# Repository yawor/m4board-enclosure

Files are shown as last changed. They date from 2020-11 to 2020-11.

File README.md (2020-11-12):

# M4 Board Enclosures Generator

This project provides OpenSCAD files for creating 3d models of some revisions of M4 Board by Duke (https://spinpoint.org) for Amstrad CPC.

It uses a [PCB Enclosure Generator](https://github.com/yawor/openscad-pcb-enclosure-generator) library.

Currently supported board revisions revisions:
- 2.5C with an edge connector
- 2.5C with an idc connector (not tested)
- 2.5B with an edge connector (not tested)
- 2.5B with an idc connector (not tested)

Ready to use STL files can be found in stl directory.

## Customizing

To customize the enclosures, clone this repository using:
```sh
git clone --recursive https://github.com/yawor/m4board-enclosure.git
```

The PCB Enclosure Generator library is added as a git submodule in pcb_enclosure directory.

Each board revision is defined in its own OpenSCAD file.

The provided files use FontAwesome and Fredoka One fonts to render texts and symbols, which you should have installed on your system, unless you plan to change them to some other fonts. These fonts use SIL OFL 1.1 and are free to download and use.

## Printed case

Images show a printed case for M4 Board rev2.5c with an edge connector. It's printed with Prusa's Galaxy Black PLA, with inserts printed with Prusa's Galaxy Silver PLA on a Prusa Mini printer.

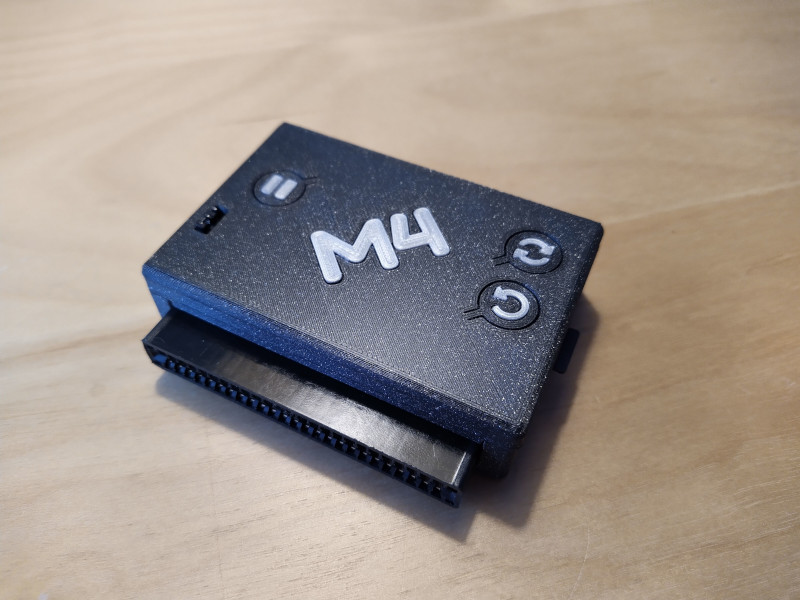
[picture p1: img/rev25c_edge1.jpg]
rev2.5c edge image1

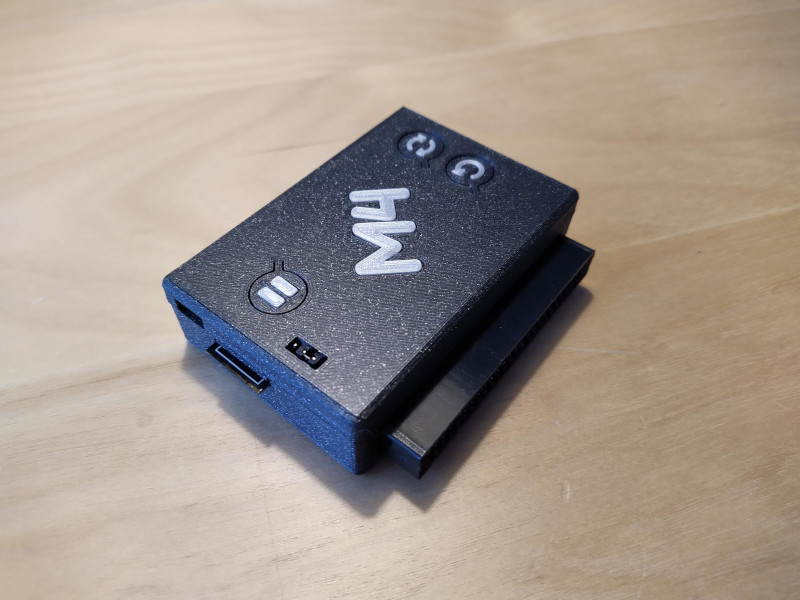
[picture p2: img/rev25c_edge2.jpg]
rev2.5c edge image2


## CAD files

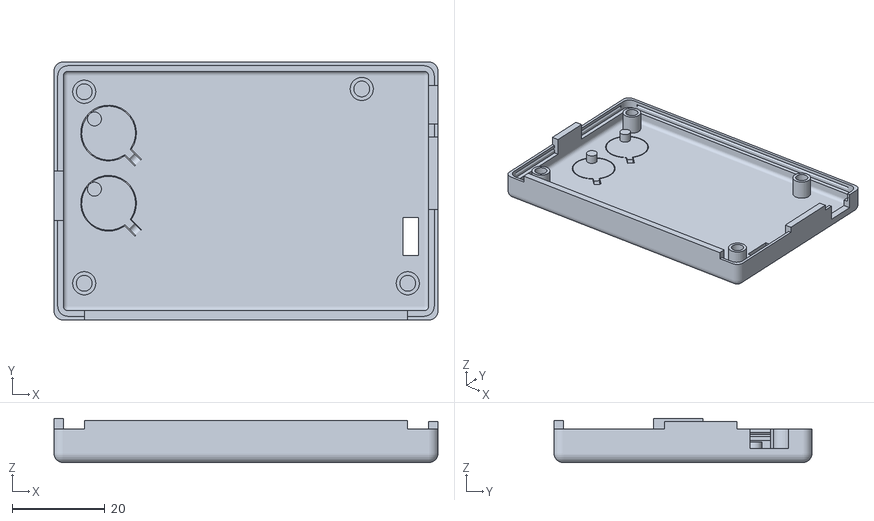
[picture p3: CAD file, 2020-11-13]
stl/m4board_rev2.5b_edge_top_notext.stl
82.6 x 55.5 x 9.50

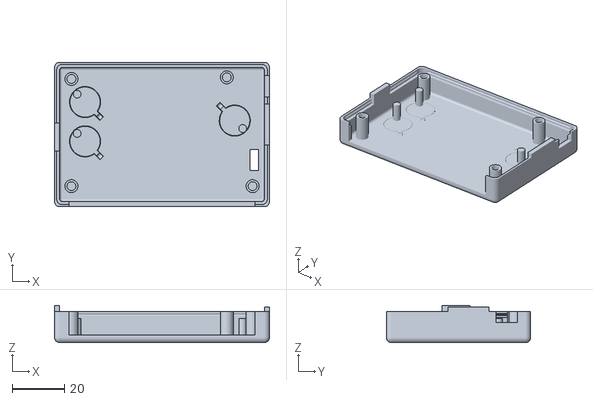
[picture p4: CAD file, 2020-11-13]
stl/m4board_rev2.5c_idc_top_notext.stl
82.6 x 55.5 x 14.3

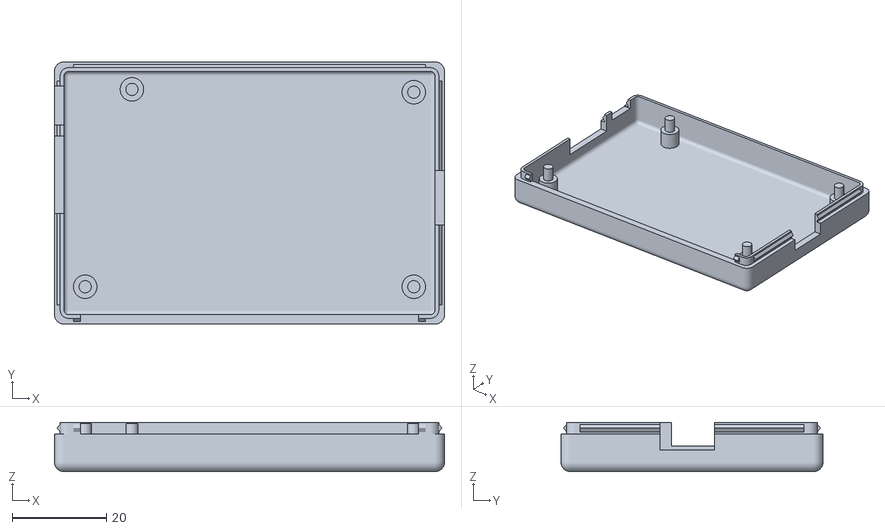
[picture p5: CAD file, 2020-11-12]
stl/m4board_rev2.5b_idc_bottom.stl
82.6 x 55.5 x 10.4

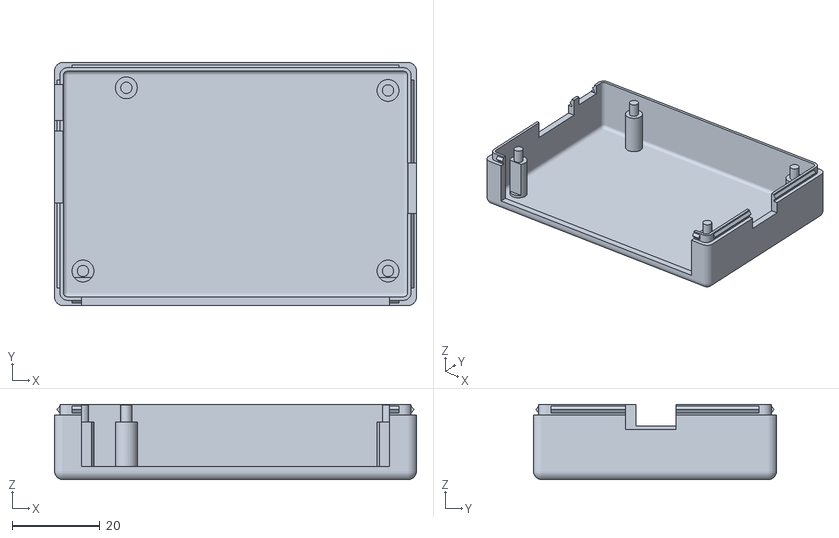
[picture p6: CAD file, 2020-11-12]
stl/m4board_rev2.5b_edge_bottom.stl
82.6 x 55.5 x 17.2

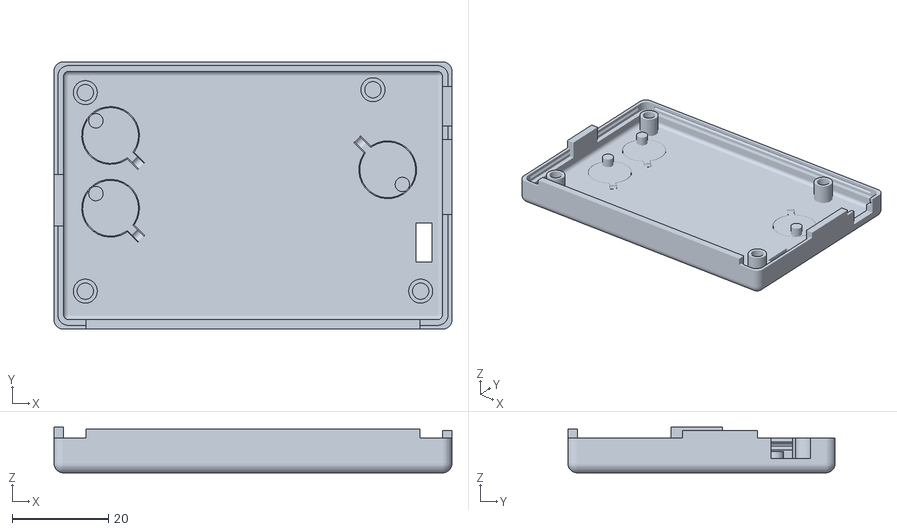
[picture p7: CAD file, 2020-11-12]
stl/m4board_rev2.5c_edge_top.stl
82.6 x 55.5 x 9.50

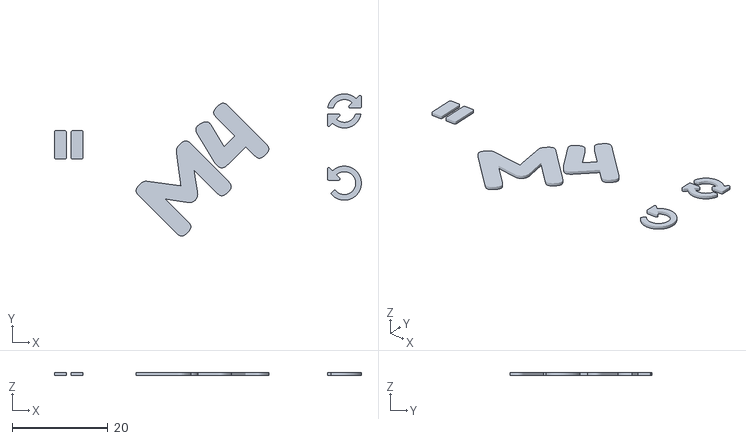
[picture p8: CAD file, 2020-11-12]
stl/m4board_rev2.5c_edge_texts.stl
64.2 x 29.7 x 0.61

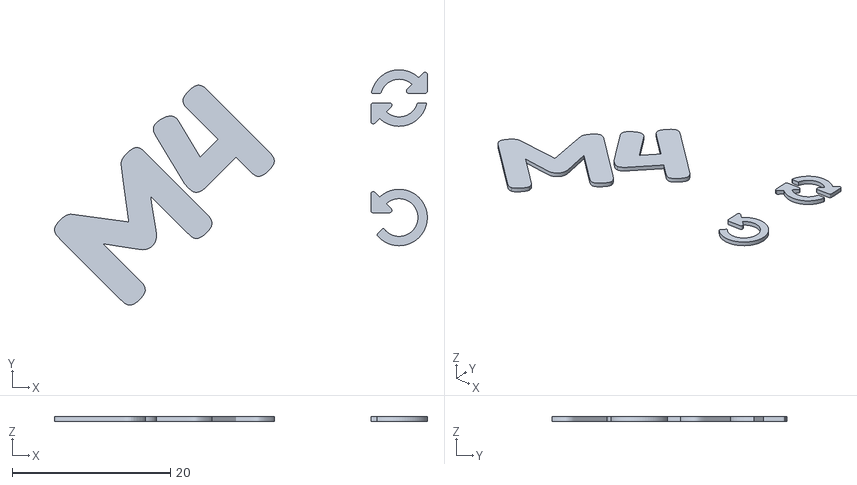
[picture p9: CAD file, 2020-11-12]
stl/m4board_rev2.5b_idc_texts.stl
47.1 x 29.7 x 0.61

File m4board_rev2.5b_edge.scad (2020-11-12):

/*
    Enclosure definition for M4Board rev 2.5B by Duke (https://www.spinpoint.org/)

    Copyright © 2020 Marcin Jaworski

    This program is free software: you can redistribute it and/or modify
    it under the terms of the GNU General Public License as published by
    the Free Software Foundation, either version 3 of the License, or
    (at your option) any later version.

    This program is distributed in the hope that it will be useful,
    but WITHOUT ANY WARRANTY; without even the implied warranty of
    MERCHANTABILITY or FITNESS FOR A PARTICULAR PURPOSE.  See the
    GNU General Public License for more details.

    You should have received a copy of the GNU General Public License
    along with this program.  If not, see <http://www.gnu.org/licenses/>
*/

use <pcb_enclosure/pcb_enclosure.scad>;

Assembled = true;
Export = "all"; // ["all", "top", "bottom", "texts"]
AddTexts = true;

/* [Hidden] */
$fn = 30;

m4Dim = [76.6, 49.5, 1.6];
m4CompBB = [[0, 0, 4], [m4Dim.x, m4Dim.y, -5]];
m4Slots = [
    ["left", [m4Dim.y - 12.7, -1.6], [m4Dim.y - 29.1, -2.6]], // antenna
    ["left", [m4Dim.y - 2.1, 4.2], [m4Dim.y - 10.3, -0.2]], // USB
    ["right", [m4Dim.y - 20, -2.3], [m4Dim.y - 31.5, -3.4]], // microSD
    ["front", [3.2, -1.9], [m4Dim.x - 3.2, -11.8]], // EXT
    ["top", [1.2, 19], [4.5, 10.9]], // power selection jumper
];
m4MountPosts = [
    [[13.4, m4Dim.y - 2.8], 3],
    [[m4Dim.x - 3.5, m4Dim.y - 3.4], 3],
    [[3.5, 4.9], 3],
    [[m4Dim.x - 3.5, 4.9], 3],
];
m4MountRestrictions = [
    [[0, 0, -12], [m4Dim.x, 3.4, -1.6]], // Area taken by the edge connector below the board
];
m4Buttons = [
    [[m4Dim.x - 5.7, m4Dim.y - 9.25], 2.8, -135], // M4board reset
    [[m4Dim.x - 5.7, m4Dim.y - 24.35], 2.8, -135], // CPC reset
];
m4Texts = AddTexts ? [
    [[m4Dim.x / 2, m4Dim.y / 2], "M4", "Fredoka One", 14, "center", "center", 45],
    [m4Buttons[0][0] - [3, -0.4], "\uf021", "FontAwesome", 6, "center", "top", 0], // symbol on M4board reset button
    [m4Buttons[1][0] - [3, -0.4], "\uf0e2", "FontAwesome", 6, "center", "top", 0], // symbol on CPC reset button
] : [];

PCBEnclosure(pcbDimensions=m4Dim, pcbComponentsBB=m4CompBB, mountPosts=m4MountPosts, mountPostsRestrictions=m4MountRestrictions, buttons=m4Buttons, slots=m4Slots, topTexts=m4Texts, textDepth=0.6, buttonDiameter=12, assembled=Assembled, export=Export);

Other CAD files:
stl/m4board_rev2.5c_edge_top_notext.stl
stl/m4board_rev2.5b_idc_top_notext.stl
stl/m4board_rev2.5c_idc_bottom.stl
stl/m4board_rev2.5b_edge_top.stl
stl/m4board_rev2.5c_idc_top.stl
stl/m4board_rev2.5c_edge_bottom.stl
stl/m4board_rev2.5b_idc_top.stl
stl/m4board_rev2.5b_bottom.stl
stl/m4board_rev2.5c_bottom.stl
m4board_rev2.5b_idc.scad
m4board_rev2.5c_edge.scad
m4board_rev2.5c_idc.scad
stl/m4board_rev2.5b_top.stl
stl/m4board_rev2.5c_top.stl

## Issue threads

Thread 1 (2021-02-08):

Way to configure the button gap size?

damieng, 2021-02-08:
Hi there, love the case and the files to create them but when I print the front face my buttons are stuck and even a knife isn't going to fix it - there's a gap on the inside of the case but the outside which was against the build plate is solid.

I couldn't see a way to configure the size of the gap around each button from the openscad file. Could that be made into a parameter for such a scenario?

yawor, 2021-02-08:
Hi,
This is probably printer dependent as I've had no issue printing this on my Prusa Mini.
If you check the pcb_enclosure.scad source, you'll see that `PCBEnclosure` module has a `buttonTolerance` argument. It's not being explicitly set from m4board_*.scad files so it uses a default value of 0.2 mm. You can either modify a default value in pcb_enclosure.scad or add your value in m4board_*.scad to `PCBEnclosure()` call.

damieng, 2021-02-09:
Thanks that looks like it has successfully modified things. I've tried doubling it to 0.4mm and will see how it prints tomorrow.

Closed 2021-02-09.

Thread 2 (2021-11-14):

Unable to print top buttons for the M4 board.

yagosan, 2021-11-14:
Hi.

I have made several tests with my Ender 3 Pro with 0.4 nozzle and PLA at 205C. And i just cant get the 3 buttons right , they always melt to the base. Please could you advise with CURA settings if possible or advise to get the top cover right for the M4 Board?. Ill really apreciate it.

Regards.,
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

yawor, 2021-11-14:
I'm sorry, I'm not familiar with CURA. I have Prusa Mini and I'm using Prusa Slicer. I've used default profile for my printer using Prusa PLA filament. I'm using standard 0.4 mm nozzle.

yawor, 2021-11-14:
You could also play with the cover parameters in the scad file, making the gap around the buttons bigger. Check the issue #1.

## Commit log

2020-11-12 Initial import
    [m4board_rev2.5b.scad, m4board_rev2.5b_bottom.stl, m4board_rev2.5b_texts.stl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]
2020-11-12 Add pictures and idc versions
    [m4board_rev2.5b_edge.scad, m4board_rev2.5b_edge_bottom.stl, m4board_rev2.5b_edge_texts.stl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]
2020-11-13 Add generated STL files for top part without embossed texts
    [m4board_rev2.5b_edge_top_notext.stl, m4board_rev2.5b_idc_top_notext.stl, m4board_rev2.5c_edge_top_notext.stl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]
